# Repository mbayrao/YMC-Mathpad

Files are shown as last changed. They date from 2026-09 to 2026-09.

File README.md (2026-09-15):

# YMC-Mathpad

## **Overview**

這是我第一次用Git…有好多操作要學…Work on it...

這款鍵盤靈感來自Summa-Congni/Mathpad，當我在2025年的某日給女朋友看到能夠方便輸入數學符號的Mathpad
她知道我喜歡也能製做出電路板，便鼓勵我著手製作此project而誕生。
此板為第一版設計，製作時有許多問題導致設計不斷變更直到最後。
主要思路為無線藍芽連接內置5V USB Type C充電電路並提供電量指示燈、有OLED螢幕可供視覺回饋挑選符號

* **Wireless**：Buletooth 5
* **Screen Size**：0.96 inch
* **Layout**：正交排列,按鍵數量6(Maxium: 12) 鍵位配置為上、下、左、右、Enter及切換下一頁的Layer鍵
* **MCU**： ESP32-C3FH4
* **Firmware**：自訂韌體(使用Arduino IDE)
* **Battery life**： 5hrs(600mAh lithium batteries)
* **Mathematical Symbols**：56個符號(一頁14個，共四頁)，根據需求還可以再擴充
* **Dimension**：101mm x 87mm x 13mm

## **Features**

使用Gateron Low Profile THT軸體搭配白色矮鍵，
0.96吋雙色I2C OLED螢幕顯示現在電量、數學符號及實際發送文字

數學符號 

Layer1： ±×÷…≤≥≠√∑∏∞αβγ

Layer2： δεμφπσθ∈∉∫∂∆∇≈

Layer3： ≅≡∪∩≃≄∨∧∴∵⊆⊇⊂⊃

Layer4： ⊗⊕⊙∀∃ℕℤℚℝℍℙρ⇒⇔

## **Repository Contents**
此 Repository 包含自行製作一把鍵盤所需的所有檔案：

| Folder | Contents |
| ----- | ----- |
| `/hardware/pcb` | KiCad/Eagle 電路圖、PCB 佈局、Gerber 製造檔、BOM |
| `/hardware/cad` | CAD 原始檔（STEP）、外殼／定位板 STEP 輸出檔 |
| `/firmware` | 韌體原始碼 |

## **Build Instructions**

1. **PCB**：使用 `/hardware/pcb/gerbers` 中的 Gerber 製造檔，向 \[JLCPCB/PCBWay/其他\] 下單製作。  
2. **Case**：使用 `/hardware/cad` 中的 STEP 檔進行 3D 列印或 CNC 加工。  
4. **Firmware**：依照Arduino IDE方式進行韌體燒錄。

## **CAD / Case Files**

* **Format**：STEP（可編輯）、STL（可直接列印）  
* **Software used**：\[Fusion 360 / FreeCAD / SolidWorks\]  
* **Location**：`hardware/cad/`

## **Wiring / Schematic**

完整電路圖 PDF：[hardware/pcb/YMC_Mathpad_v1.pdf](https://github.com/mbayrao/YMC-Mathpad/blob/main/Hardware/YMC_Mathpad_v1.pdf)

## **Credits / Acknowledgments**

本專案受到 [Mathpad](https://github.com/Summa-Cogni/Mathpad)（作者：\[nup002\dancergraham]）的啟發，並以其為基礎進行開發。

## **Disclaimer**

本專案為業餘／開源專案，以「現況」提供，不提供任何保固。下單或焊接前，請確認所有元件的規格與額定值符合需求。

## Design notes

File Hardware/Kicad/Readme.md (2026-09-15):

Mathpad PCB files

This folder contains the schematics and design files for the Mathpad PCB.

The folder kicad contains the full KiCAD project file. Download the open source KiCAD EDA to open it.

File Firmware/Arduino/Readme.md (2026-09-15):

# This Firmware using 

 **libraries**

-NimBLE-Arduino(*IT WORKS ON VER.1.4.3*)

-BleKeyboard.h

-U8g2lib.h

-Keypad.h

 **LCD Image Converter tool**
* https://www.teachmemicro.com/lcd-bitmap-converter-online/

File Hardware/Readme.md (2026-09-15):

# Hardware resources

This folder contains everything related to the hardware of the Mathpad:
- Printed circuit board

The files contained in this folder are licensed under [CERN Open Hardware Licence Version 2 - Strongly Reciprocal](https://cern-ohl.web.cern.ch).

## What you CAN do:
- Use the design files to make products for yourself
- Modify the design files to suit your needs
- Share and distribute the original design files
- Share and distribute your modified design files
- Use the designs commercially and sell products you make

## What you MUST do:
- Keep all the original license notices and copyright information
- If you modify the files, add a notice stating what you changed and when
- When sharing products you've made, you must either:
	1) Provide the complete source files with the product, OR
	2) Clearly inform recipients where they can get the complete source files
- License any modifications you make under the same CERN-OHL-S license
- Display the source location on the product itself if specified in a notice

## What you CANNOT do:
- Remove or alter the original license notices
- Use a different license for your modifications
- Restrict others from exercising the rights granted by this license
- Hold the original creators liable for any issues with the designs

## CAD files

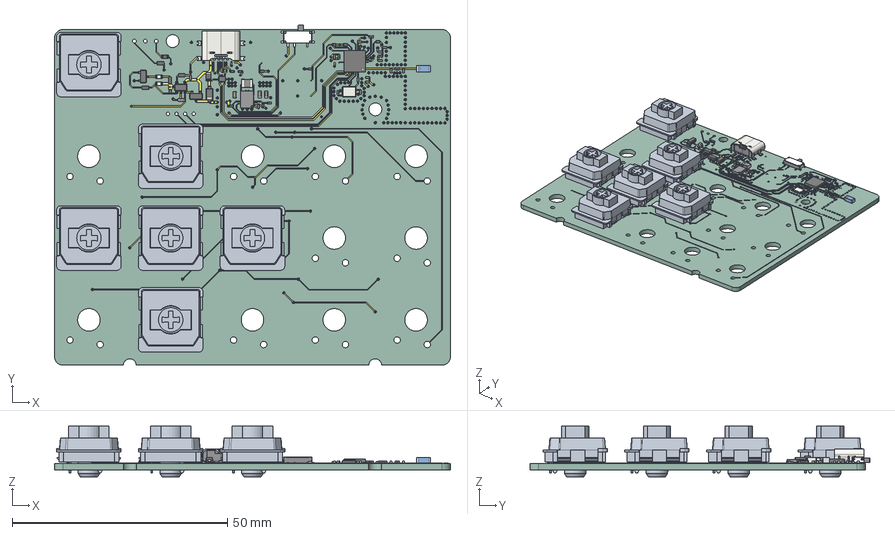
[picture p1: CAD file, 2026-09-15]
Hardware/Kicad/Mathpad.step
92.0 x 79.1 x 11.8 mm
R_0402_1005Metric x 11
LED_0603_1608Metric x 2
R_0603_1608Metric x 5
C_0402_1005Metric x 15
MSK12C02
D_SOD-123
SOT-23-5
Mathpad 1.11.1 x 6
QFN-32-1EP_5x5mm_P0.5mm_EP3.7x3.7mm
L_0402_1005Metric x 3
Crystal_SMD_3225-4Pin_3.2x2.5mm
ANT3216LL00R2400A
Fuse_0805_2012Metric
C_0603_1608Metric x 4
L_1008_2520Metric
SOT-666
ThermalPin
PinsArrayLR
SOT-23 x 2
USB_C_Receptacle_GCT_USB4135-GF-A_6P_TopMnt_Horizontal
Mathpad_copper
Mathpad_via
Mathpad_PCB

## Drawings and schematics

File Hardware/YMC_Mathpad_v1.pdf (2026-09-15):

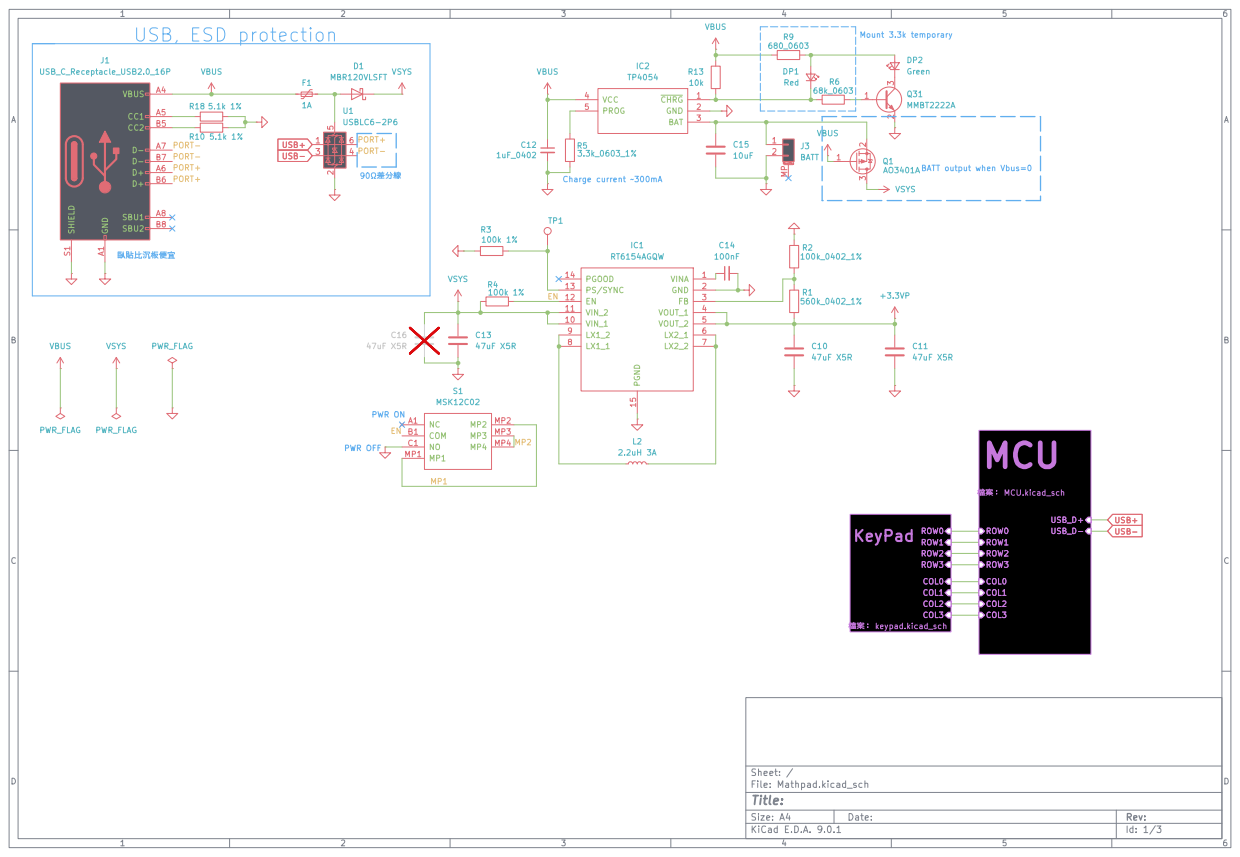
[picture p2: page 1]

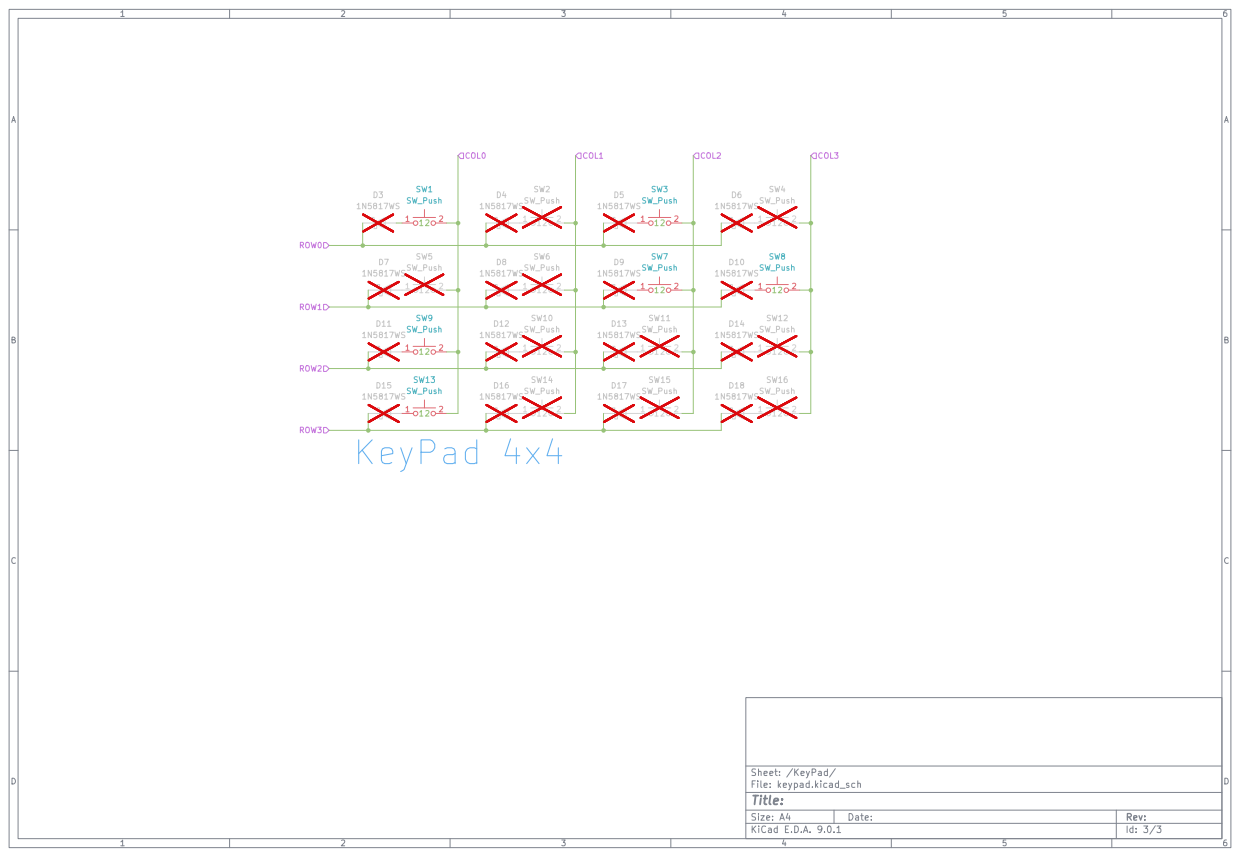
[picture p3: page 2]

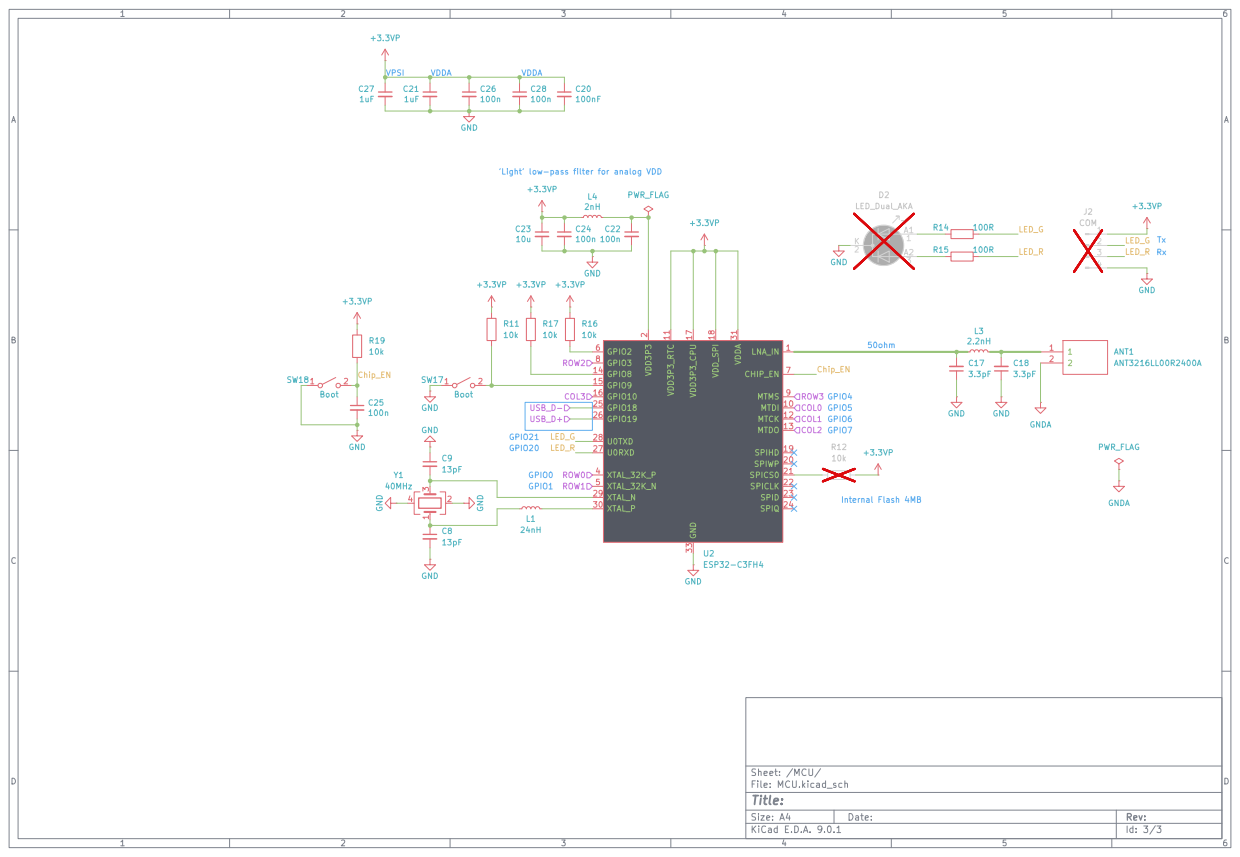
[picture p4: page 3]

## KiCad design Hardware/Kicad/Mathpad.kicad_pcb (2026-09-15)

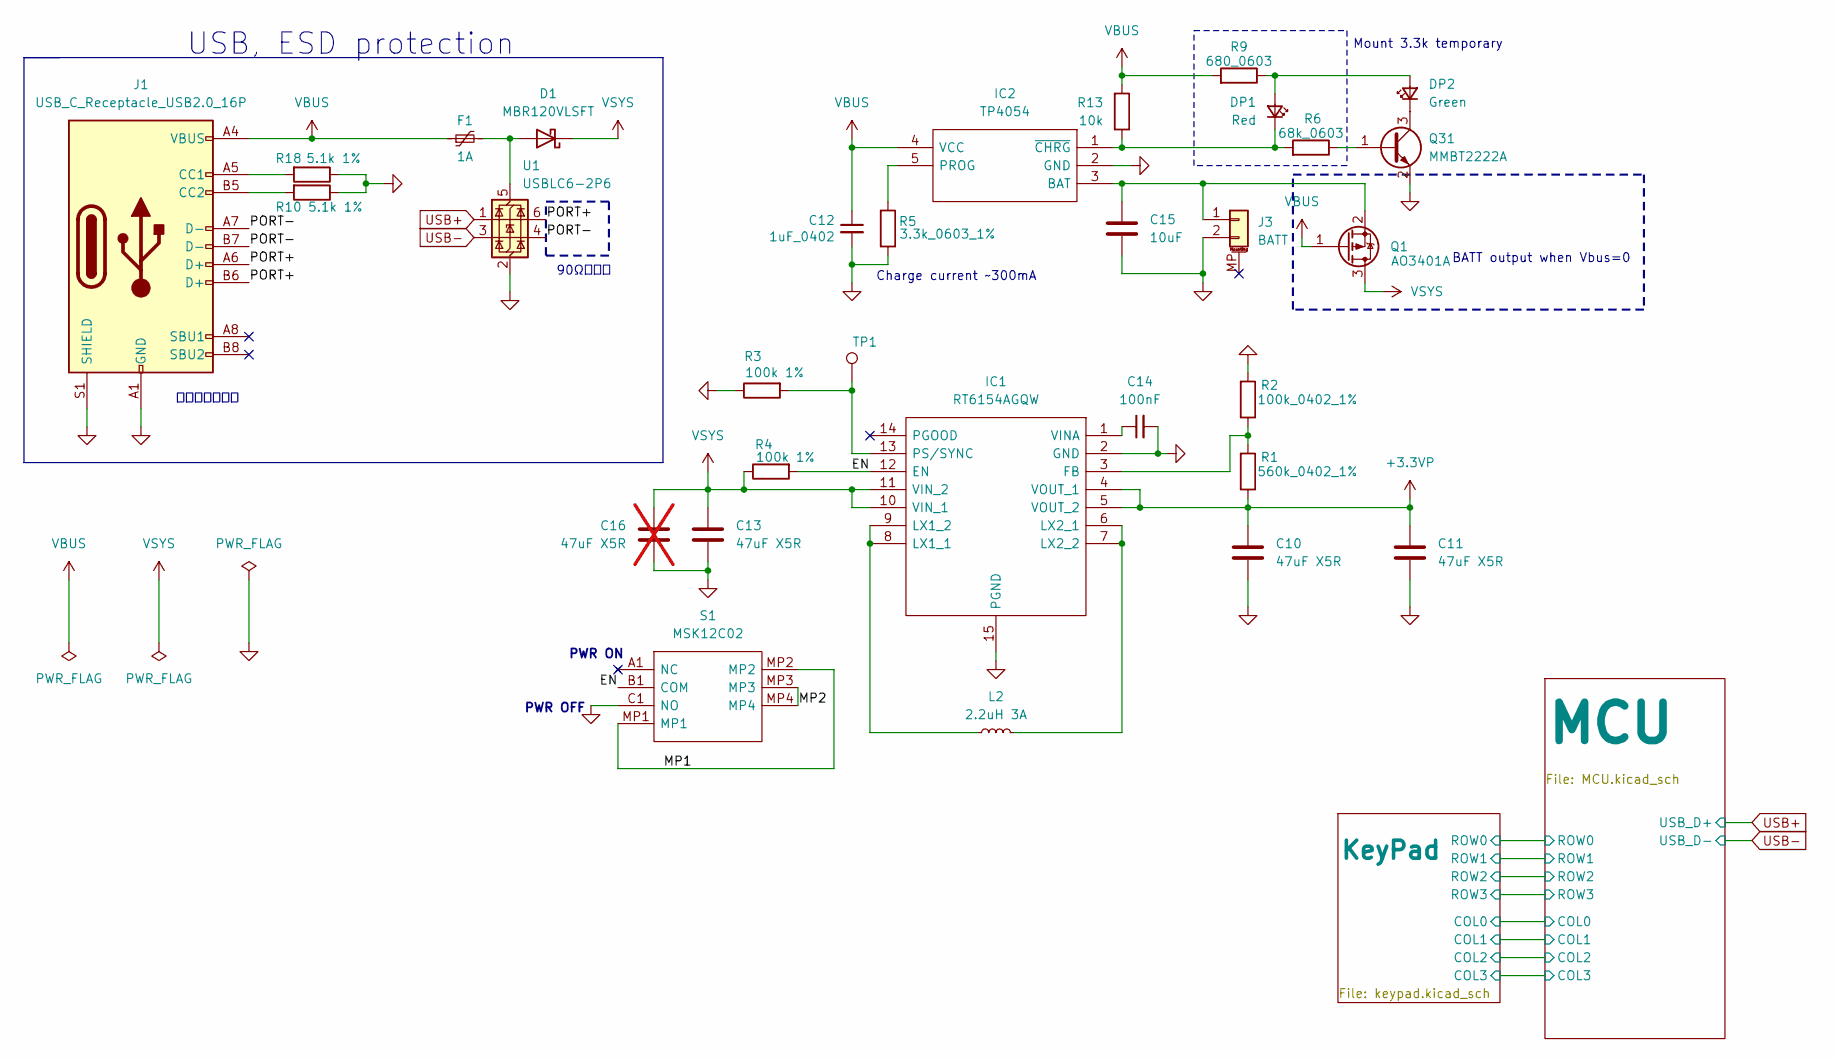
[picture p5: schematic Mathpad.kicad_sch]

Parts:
C10, C11, C13: 47uF X5R; C_0603_1608Metric; LCSC Part # C140782
C12: 1uF_0402; C_0402_1005Metric; LCSC Part # C52923
C14: 100nF; C_0402_1005Metric; LCSC Part # C85858
C15: 10uF; C_0603_1608Metric; LCSC Part # C6119842
C16: 47uF X5R; C_0603_1608Metric; LCSC Part # C140782; not fitted
D1: MBR120VLSFT; D_SOD-123; LCSC Part # C223608
DP1: Red; LED_0603_1608Metric; LCSC Part # C965799
DP2: Green; LED_0603_1608Metric; LCSC Part # C22371297
F1: 1A; Fuse_0805_2012Metric; MPN BSMD0805-050-24V; LCSC C910822
IC1: RT6154AGQW; SON50P300X400X80-15N-D; Manufacturer_Part_Number RT6154AGQW; Mouser Part Number 835-RT6154AGQW
IC2: TP4054; SOT-23-5; Manufacturer_Part_Number TP4054; LCSC Part # C5381776
J1: USB_C_Receptacle_USB2.0_16P; USB_C_Receptacle_GCT_USB4110; LCSC Part # C5187472
J3: BATT; JST_ZH_S2B-ZR-SM4A-TF_1x02-1MP_P1.50mm_Horizontal; LCSC Part # C19272405
L2: 2.2uH 3A; L_1008_2520Metric; LCSC Part # C5832372
Q1: AO3401A; SOT-23; LCSC Part # C15127
Q31: MMBT2222A; SOT-23; LCSC Part # C82460
R1: 560k_0402_1%; R_0402_1005Metric; MPN 0402WGF5101TCE; LCSC C137958
R2: 100k_0402_1%; R_0402_1005Metric; MPN 0402WGF5101TCE; LCSC C60491
R3, R4: 100k 1%; R_0402_1005Metric; MPN 0402WGF5101TCE; LCSC C60491
R5: 3.3k_0603_1%; R_0603_1608Metric; LCSC C22978
R6: 68k_0603; R_0603_1608Metric; LCSC C22978
R9: 680_0603; R_0603_1608Metric; LCSC C22978
R10, R18: 5.1k 1%; R_0402_1005Metric; MPN 0402WGF5101TCE; LCSC C25905
R13: 10k; R_0402_1005Metric; LCSC Part # C60490
S1: MSK12C02; Manufacturer_Part_Number MSK12C02; LCSC Part # C431540
TP1: TestPoint; TestPoint_Pad_1.5x1.5mm
U1: USBLC6-2P6; SOT-666; LCSC Part # C15999

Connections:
+3.3VP: C10.1, C11.1, IC1.4 (VOUT_1), IC1.5 (VOUT_2), R1.1; also elsewhere on the board
/EN: IC1.12 (EN), R4.2, S1.B1 (COM)
/MP1: S1.MP1, S1.MP2
/MP2: S1.MP3, S1.MP4
/PORT+: J1.A6 (D+), J1.B6 (D+), U1.6 (I/O1)
/PORT-: J1.A7 (D-), J1.B7 (D-), U1.4 (I/O2)
GND: C10.2, C11.2, C12.2, C13.2, C14.2, C15.2, C16.2, IC1.2 (GND), IC1.15 (PGND), IC2.2 (GND), J1.A1 (GND), J1.A12 (GND), J1.B1 (GND), J1.B12 (GND), J1.S1 (SHIELD), J3.2, Q31.2 (E), R2.2, R3.1, R5.1, R10.1, R18.1, S1.C1 (NO), U1.2 (GND); also elsewhere on the board
unnamed: D1.2 (A), F1.2, U1.5 (VBUS)
unnamed: DP1.1 (K), IC2.1 (~CHRG), R6.2, R13.1
unnamed: DP2.1 (K), Q31.3 (C)
unnamed: IC1.3 (FB), R1.2, R2.1
unnamed: IC1.8 (LX1_1), IC1.9 (LX1_2), L2.2
unnamed: IC1.6 (LX2_1), IC1.7 (LX2_2), L2.1
unnamed: IC1.13 (PS/SYNC), R3.2, TP1.1
unnamed: C14.1, IC1.1 (VINA)
unnamed: C15.1, IC2.3 (BAT), J3.1, Q1.2 (S)
unnamed: IC2.5 (PROG), R5.2
unnamed: J1.A5 (CC1), R18.2
unnamed: J1.B5 (CC2), R10.2
unnamed: Q31.1 (B), R6.1
USB+: U1.1 (I/O1); also elsewhere on the board
USB-: U1.3 (I/O2); also elsewhere on the board
VSYS: C13.1, C16.1, D1.1 (K), IC1.10 (VIN_1), IC1.11 (VIN_2), Q1.3 (D), R4.1

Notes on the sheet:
90Ω差分線
USB, ESD protection
Mount 3.3k temporary
PWR ON
PWR OFF
臥貼比沉板便宜
Charge current ~300mA
BATT output when Vbus=0

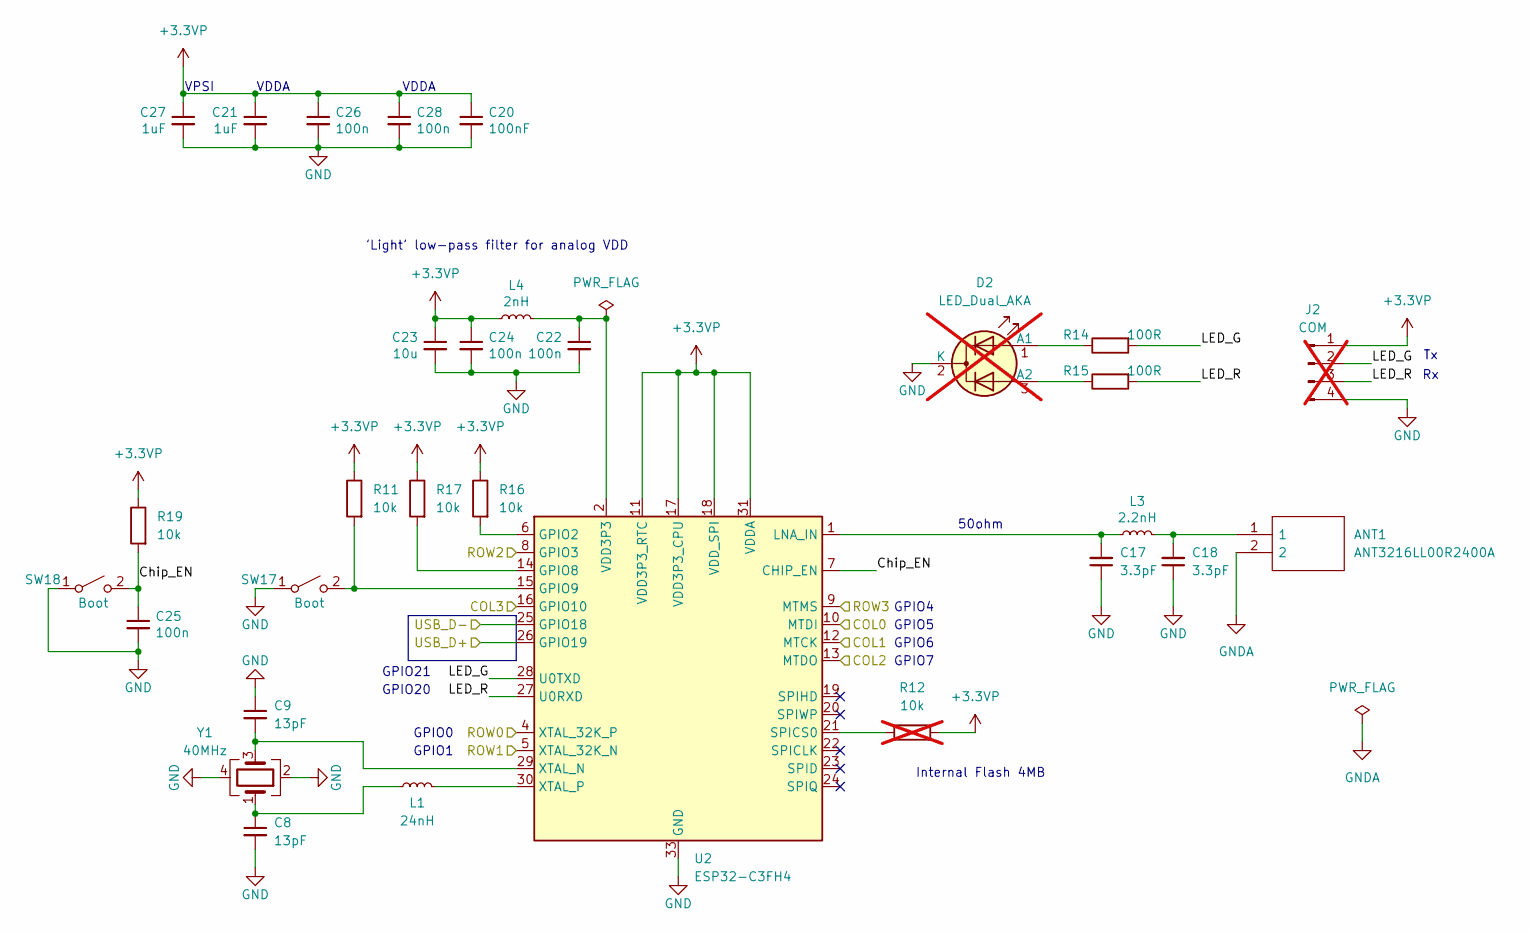
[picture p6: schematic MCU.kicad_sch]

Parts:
ANT1: ANT3216LL00R2400A; Manufacturer_Part_Number ANT3216LL00R2400A; Mouser Part Number 603-ANT3216LL00R2400
C8, C9: 13pF; C_0402_1005Metric; LCSC Part # C45359988
C17, C18: 3.3pF; C_0402_1005Metric; LCSC Part # C76906
C20: 100nF; C_0402_1005Metric; LCSC Part # C1525
C21, C27: 1uF; C_0402_1005Metric; LCSC Part # C52923
C22, C24, C25, C26, C28: 100n; C_0402_1005Metric; LCSC Part # C1525
C23: 10u; C_0402_1005Metric; LCSC Part # C76991
D2: LED_Dual_AKA; LED_D3.0mm-3; not fitted
J2: COM; PinHeader_1x04_P2.00mm_Vertical; not fitted
L1: 24nH; L_0402_1005Metric; LCSC Part # C330863
L3: 2.2nH; L_0402_1005Metric; LCSC Part # C86061
L4: 2nH; L_0402_1005Metric; LCSC Part # C18216
R11, R16, R17, R19: 10k; R_0402_1005Metric; LCSC Part # C60490
R12: 10k; R_0402_1005Metric; LCSC Part # C60490; not fitted
R14, R15: 100R; R_0603_1608Metric; LCSC Part # C105588
SW17, SW18: Boot; SW_Push_SPST_NO_Alps_SKRK; LCSC Part # C18077675
U2: ESP32-C3FH4; QFN-32-1EP_5x5mm_P0.5mm_EP3.7x3.7mm; LCSC Part # C2858491
Y1: 40MHz; Crystal_SMD_3225-4Pin_3.2x2.5mm; LCSC Part # C18221407

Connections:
+3.3VP: C20.1, C21.1, C23.1, C24.1, C26.1, C27.1, C28.1, J2.1, L4.1, R11.1, R12.2, R16.1, R17.1, R19.1, U2.11 (VDD3P3_RTC), U2.17 (VDD3P3_CPU), U2.18 (VDD_SPI), U2.31 (VDDA), U2.32 (VDDA); also elsewhere on the board
/KeyPad/COL0: U2.10 (MTDI); also elsewhere on the board
/KeyPad/COL1: U2.12 (MTCK); also elsewhere on the board
/KeyPad/COL2: U2.13 (MTDO); also elsewhere on the board
/KeyPad/COL3: U2.16 (GPIO10); also elsewhere on the board
/KeyPad/ROW0: U2.4 (XTAL_32K_P); also elsewhere on the board
/KeyPad/ROW1: U2.5 (XTAL_32K_N); also elsewhere on the board
/KeyPad/ROW2: U2.8 (GPIO3); also elsewhere on the board
/KeyPad/ROW3: U2.9 (MTMS); also elsewhere on the board
/MCU/Chip_EN: C25.1, R19.2, SW18.2 (B), U2.7 (CHIP_EN)
/MCU/LED_G: J2.2, R14.2, U2.28 (U0TXD)
/MCU/LED_R: J2.3, R15.2, U2.27 (U0RXD)
GND: C8.2, C9.1, C17.1, C18.1, C20.2, C21.2, C22.2, C23.2, C24.2, C25.2, C26.2, C27.2, C28.2, D2.2 (K), J2.4, SW17.1 (A), SW18.1 (A), U2.33 (GND), Y1.2, Y1.4; also elsewhere on the board
GNDA: ANT1.2
unnamed: ANT1.1, C18.2, L3.2
unnamed: C8.1, L1.1, Y1.1
unnamed: C22.1, L4.2, U2.2 (VDD3P3), U2.3 (VDD3P3)
unnamed: D2.1 (A1), R14.1
unnamed: D2.3 (A2), R15.1
unnamed: R11.2, SW17.2 (B), U2.15 (GPIO9)
unnamed: R16.2, U2.6 (GPIO2)
unnamed: R17.2, U2.14 (GPIO8)
unnamed: C17.2, L3.1, U2.1 (LNA_IN)
unnamed: R12.1, U2.21 (SPICS0)
unnamed: C9.2, U2.29 (XTAL_N), Y1.3
unnamed: L1.2, U2.30 (XTAL_P)
USB+: U2.26 (GPIO19); also elsewhere on the board
USB-: U2.25 (GPIO18); also elsewhere on the board

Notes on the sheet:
GPIO1
GPIO4
GPIO5
VPSI
GPIO6
VDDA
GPIO20
GPIO21
GPIO7
GPIO0
'Light' low-pass filter for analog VDD
50ohm
Internal Flash 4MB

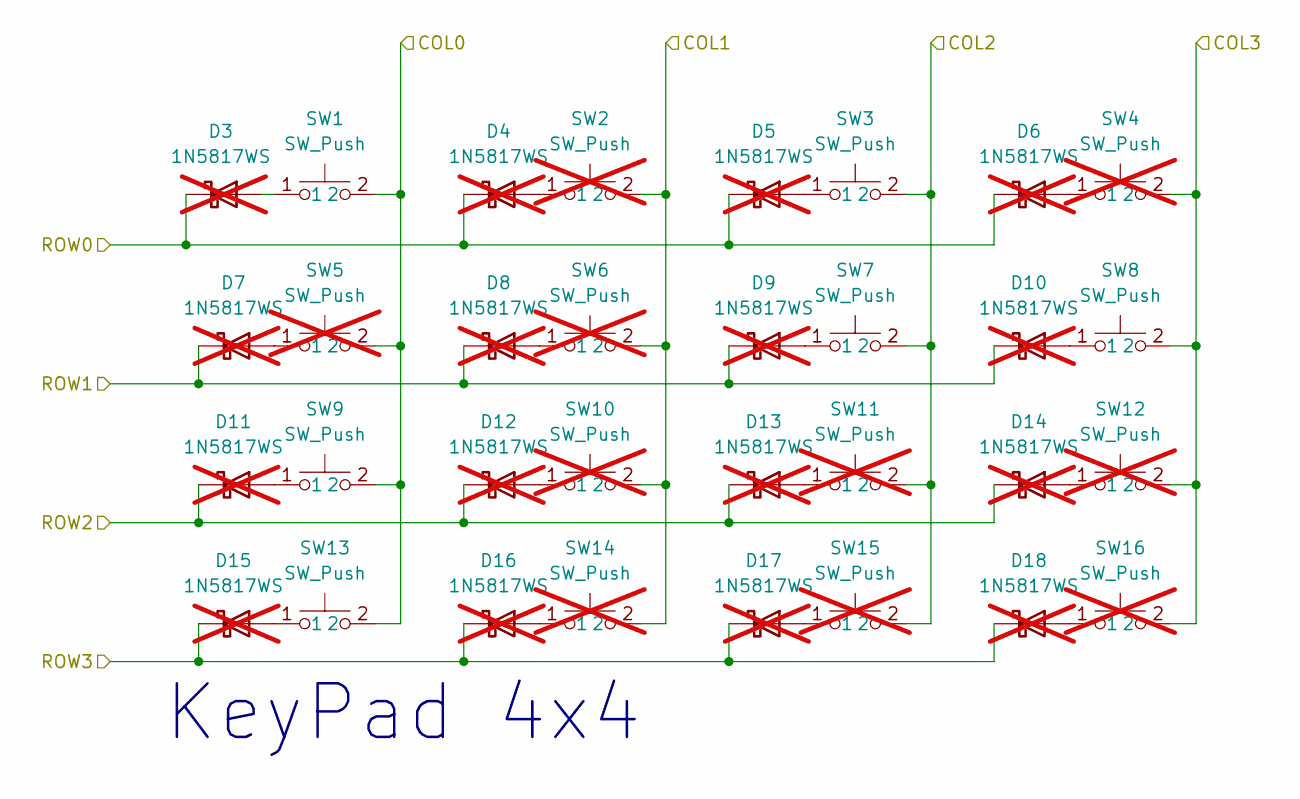
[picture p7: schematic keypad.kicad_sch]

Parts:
D3, D4, D5, D6, D7, D8, D9, D10, D11, D12, D13, D14, D15, D16, D17, D18: 1N5817WS; D_SOD-123; LCSC Part # C727113; not fitted
SW1, SW3, SW7, SW8, SW9, SW13: SW_Push; SW_Gateron_LowProfile_THT
SW2, SW4, SW5, SW6, SW10, SW11, SW12, SW14, SW15, SW16: SW_Push; SW_Gateron_LowProfile_THT; not fitted

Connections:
/KeyPad/COL0: SW1.2, SW5.2, SW9.2, SW13.2; also elsewhere on the board
/KeyPad/COL1: SW2.2, SW6.2, SW10.2, SW14.2; also elsewhere on the board
/KeyPad/COL2: SW3.2, SW7.2, SW11.2, SW15.2; also elsewhere on the board
/KeyPad/COL3: SW4.2, SW8.2, SW12.2, SW16.2; also elsewhere on the board
/KeyPad/ROW0: D3.1 (K), D4.1 (K), D5.1 (K), D6.1 (K); also elsewhere on the board
/KeyPad/ROW1: D7.1 (K), D8.1 (K), D9.1 (K), D10.1 (K); also elsewhere on the board
/KeyPad/ROW2: D11.1 (K), D12.1 (K), D13.1 (K), D14.1 (K); also elsewhere on the board
/KeyPad/ROW3: D15.1 (K), D16.1 (K), D17.1 (K), D18.1 (K); also elsewhere on the board
unnamed: D3.2 (A), SW1.1
unnamed: D4.2 (A), SW2.1
unnamed: D5.2 (A), SW3.1
unnamed: D6.2 (A), SW4.1
unnamed: D7.2 (A), SW5.1
unnamed: D8.2 (A), SW6.1
unnamed: D9.2 (A), SW7.1
unnamed: D10.2 (A), SW8.1
unnamed: D11.2 (A), SW9.1
unnamed: D12.2 (A), SW10.1
unnamed: D13.2 (A), SW11.1
unnamed: D14.2 (A), SW12.1
unnamed: D15.2 (A), SW13.1
unnamed: D16.2 (A), SW14.1
unnamed: D17.2 (A), SW15.1
unnamed: D18.2 (A), SW16.1

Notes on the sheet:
KeyPad 4x4

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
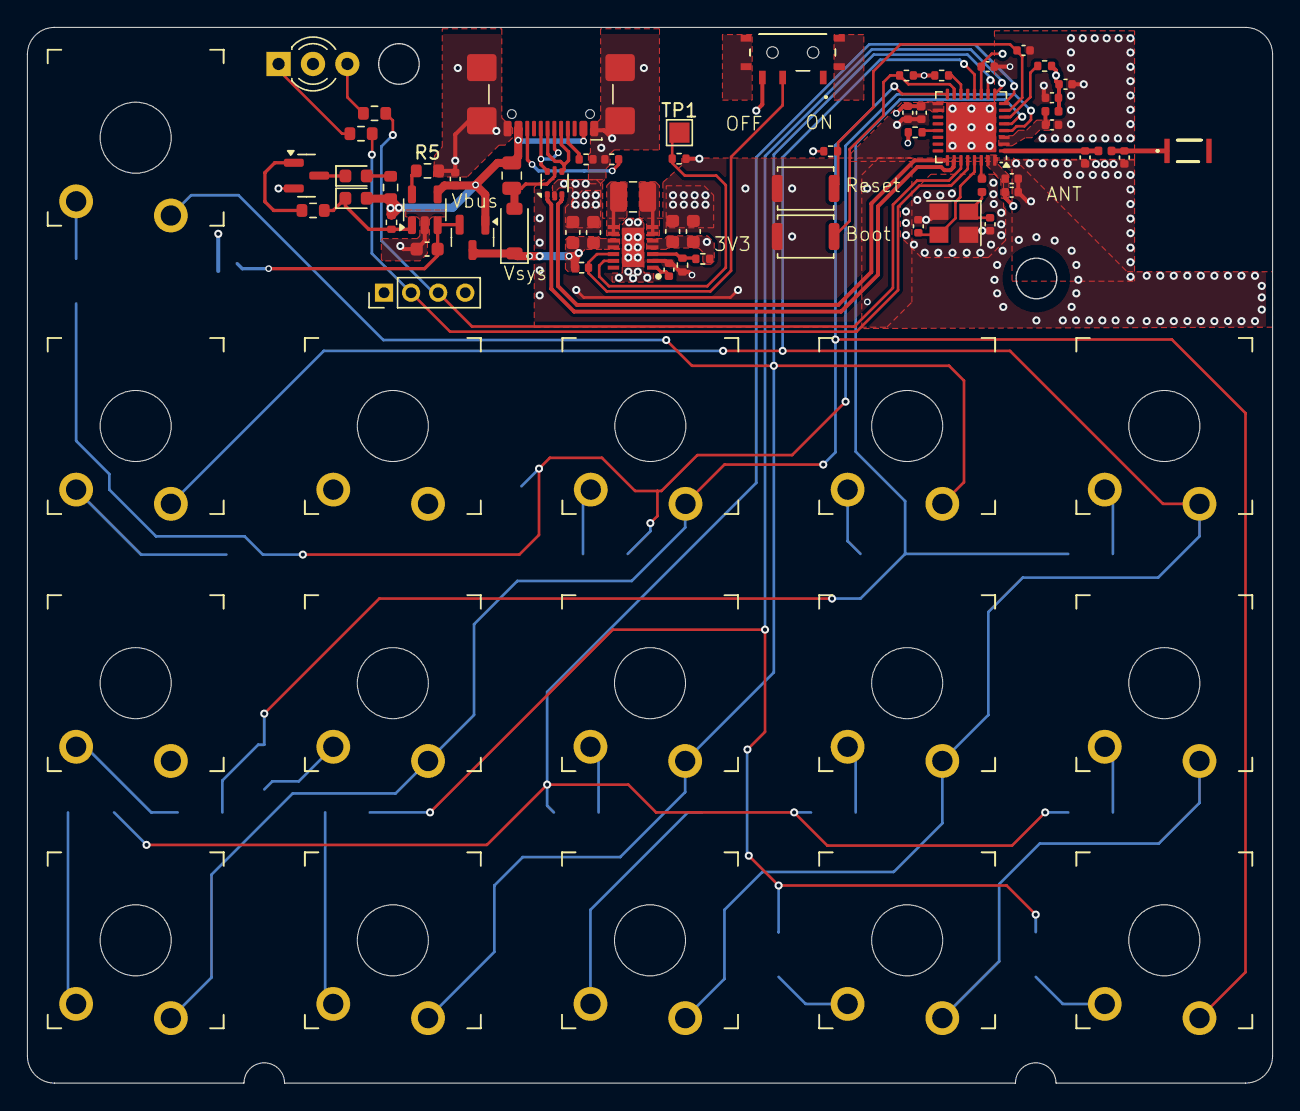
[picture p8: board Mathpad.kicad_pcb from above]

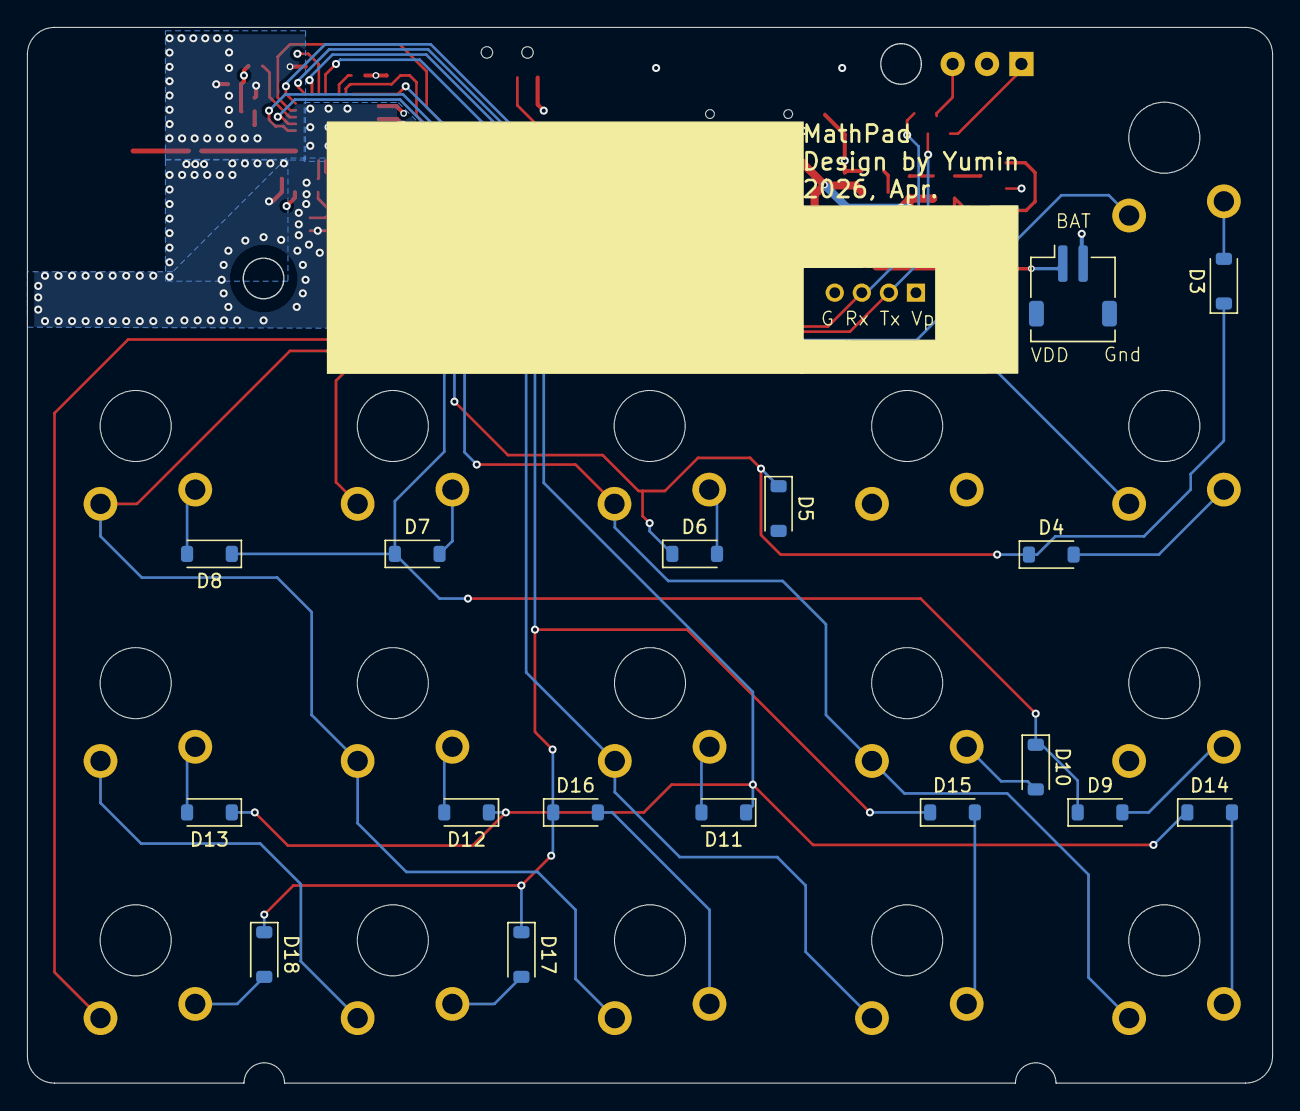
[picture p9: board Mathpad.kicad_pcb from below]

Board: 4 copper layers, 92.0 x 78.0 mm, 93 parts (17 on the bottom side), 64 nets.

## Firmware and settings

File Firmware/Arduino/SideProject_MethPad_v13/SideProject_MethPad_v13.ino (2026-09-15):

// v13 - add Layer 4
#include <BleKeyboard.h>
BleKeyboard bleKeyboard("YMC-BLE_KB", "Mendako Lab", 50); // 50 僅為初始宣告值
#define USE_NIMBLE

#include <Wire.h>
#include <U8g2lib.h>
#include <Keypad.h>

U8G2_SSD1306_128X64_NONAME_F_HW_I2C u8g2(U8G2_R0, /* reset=*/ U8X8_PIN_NONE, /* clock=*/ 21, /* data=*/ 20);

// --- 2x4 鍵盤設定 ---
const byte ROWS = 2; 
const byte COLS = 4; 
char keys[ROWS][COLS] = {
  { 1, 2, 3, 4 },
  { 5, 6, 7, 8 }
};
byte rowPins[ROWS] = { 0, 1 };      
byte colPins[COLS] = { 5, 6, 7, 10 }; 
Keypad keypad = Keypad(makeKeymap(keys), rowPins, colPins, ROWS, COLS);

// --- 電池偵測硬體設定 ---
#define BATTERY_PIN 3            // 電池分壓接至 GPIO3
int batteryLevel = 100;          // 全域變數：儲存目前的電量百分比 (0-100)
unsigned long lastBatteryCheck = 0; // 記錄上次檢查電池的時間
const unsigned long batteryInterval = 5000; // 每 60,000 毫秒 (1分鐘) 檢查一次

// --- 狀態變數 ---
uint8_t currentLayer = 1; 
int currentCursor = 0;    
float adcValue=0;
int percentage=0;
// ---- LaTeX 輸出字串對應 ----
const char* symbolShortcuts[4][14] = {
  { "\\pm%/#",     "\\times%/#",    "\\div%/#",  "\\dots%/#",   "\\le%/#",     "\\ge%/#",     "\\neq%/#",    "\\sqrt%/#",   "\\sum%/#",        "\\prod%/#",     "\\infty%/#",    "\\alpha%/#",    "\\beta%/#",    "\\gamma%/#"   },
  { "\\delta%/#",  "\\epsilon%/#",  "\\mu%/#",   "\\phi%/#",    "\\pi%/#",     "\\sigma%/#",  "\\theta%/#",  "\\in%/#",     "\\nin%/#",        "\\int%/#",      "\\partial%/#",  "\\Delta%/#",    "\\nabla%/#",   "\\approx%/#", },
  { "\\cong%/#",   "\\equiv%/#",    "\\cup%/#",  "\\cap%/#",    "\\simeq%/#",  "\\not%/#",    "\\vee%/#",    "\\wedge%/#",  "\\therefore%/#",  "\\because%/#",  "\\sube%/#",     "\\supe%/#",     "\\sub%/#",     "\\sup%/#",    },
  { "\\krone%/#",  "\\exclus%/#",   "\\hadam%/#","\\forall%/#", "\\existe%/#", "\\natur%/#",  "\\integ%/#",  "\\ratio%/#",  "\\real%/#",       "\\Quat%/#",     "\\prime%/#",    "\\rho%/#",      "\\ifthen%/#",  "\\ifaoif%/#"}
};


// =========================================================================
// https://www.teachmemicro.com/lcd-bitmap-converter-online/
// =========================================================================

// --- LAYER 1 (共14個) ---
const uint8_t bmp_L1_0[32] PROGMEM = { 0x00,0x00,0x01,0x80,0x01,0x80,0x01,0x80,0x01,0x80,0x1F,0xF8,0x1F,0xF8,0x01,0x80,0x01,0x80,0x01,0x80,0x01,0x80,0x00,0x00,0x1F,0xF8,0x1F,0xF8,0x00,0x00,0x00,0x00 }; // ±
const uint8_t bmp_L1_1[32] PROGMEM = { 0x00,0x00,0x00,0x00,0x00,0x00,0x10,0x08,0x08,0x10,0x04,0x20,0x02,0x40,0x01,0x80,0x01,0x80,0x02,0x40,0x04,0x20,0x08,0x10,0x10,0x08,0x00,0x00,0x00,0x00,0x00,0x00 }; // ×
const uint8_t bmp_L1_2[32] PROGMEM = { 0x00,0x00,0x00,0x00,0x00,0x00,0x00,0x00,0x01,0x80,0x01,0x80,0x00,0x00,0x1F,0xF8,0x1F,0xF8,0x00,0x00,0x01,0x80,0x01,0x80,0x00,0x00,0x00,0x00,0x00,0x00,0x00,0x00 }; // ÷
const uint8_t bmp_L1_3[32] PROGMEM = { 0x00,0x00,0x00,0x00,0x00,0x00,0x00,0x00,0x00,0x00,0x00,0x00,0x00,0x00,0x00,0x00,0x00,0x00,0x00,0x00,0x00,0x00,0x33,0x30,0x33,0x30,0x00,0x00,0x00,0x00,0x00,0x00 }; // …
const uint8_t bmp_L1_4[32] PROGMEM = { 0x00,0x00,0x00,0x00,0x00,0x00,0x00,0x18,0x00,0x60,0x01,0x80,0x06,0x00,0x18,0x00,0x06,0x00,0x01,0x80,0x00,0x60,0x00,0x18,0x00,0x00,0x1F,0xF8,0x00,0x00,0x00,0x00 }; // ≤
const uint8_t bmp_L1_5[32] PROGMEM = { 0x00,0x00,0x00,0x00,0x00,0x00,0x18,0x00,0x06,0x00,0x01,0x80,0x00,0x60,0x00,0x18,0x00,0x60,0x01,0x80,0x06,0x00,0x18,0x00,0x00,0x00,0x1F,0xF8,0x00,0x00,0x00,0x00 }; // ≥
const uint8_t bmp_L1_6[32] PROGMEM = { 0x00,0x00,0x00,0x00,0x00,0x00,0x00,0x08,0x00,0x10,0x00,0x20,0x1F,0xF8,0x00,0x80,0x01,0x00,0x1F,0xF8,0x04,0x00,0x08,0x00,0x10,0x00,0x00,0x00,0x00,0x00,0x00,0x00 }; // ≠
const uint8_t bmp_L1_7[32] PROGMEM = { 0x00,0x00,0x00,0x00,0x00,0x0E,0x00,0x10,0x00,0x10,0x00,0x20,0x00,0x20,0x00,0x40,0x30,0x40,0x08,0x80,0x08,0x80,0x05,0x00,0x05,0x00,0x02,0x00,0x02,0x00,0x00,0x00 }; // √
const uint8_t bmp_L1_8[32] PROGMEM = { 0x00,0x00,0x00,0x00,0x1F,0xF8,0x10,0x18,0x08,0x08,0x04,0x00,0x02,0x00,0x01,0x00,0x00,0x80,0x01,0x00,0x02,0x00,0x04,0x00,0x08,0x08,0x10,0x18,0x1F,0xF8,0x00,0x00 }; // ∑
const uint8_t bmp_L1_9[32] PROGMEM = { 0x00,0x00,0x00,0x00,0x00,0x00,0x1F,0xF8,0x04,0x20,0x04,0x20,0x04,0x20,0x04,0x20,0x04,0x20,0x04,0x20,0x04,0x20,0x04,0x20,0x04,0x20,0x00,0x00,0x00,0x00,0x00,0x00 }; // ∏
const uint8_t bmp_L1_10[32] PROGMEM= { 0x00,0x00,0x00,0x00,0x00,0x00,0x00,0x00,0x00,0x00,0x00,0x00,0x0C,0x18,0x12,0x24,0x21,0x42,0x20,0x82,0x21,0x42,0x12,0x24,0x0C,0x18,0x00,0x00,0x00,0x00,0x00,0x00 }; // ∞
const uint8_t bmp_L1_11[32] PROGMEM= { 0x00,0x00,0x00,0x00,0x00,0x00,0x00,0x00,0x00,0x00,0x07,0x20,0x08,0xA0,0x08,0x40,0x08,0x40,0x08,0x40,0x08,0x40,0x08,0xA0,0x07,0x20,0x00,0x00,0x00,0x00,0x00,0x00 }; // α
const uint8_t bmp_L1_12[32] PROGMEM= { 0x00,0x00,0x00,0x00,0x07,0x00,0x08,0x80,0x08,0x80,0x08,0x80,0x0F,0x80,0x08,0x40,0x08,0x40,0x08,0x40,0x0C,0x40,0x0B,0x80,0x08,0x00,0x08,0x00,0x00,0x00,0x00,0x00 }; // β
const uint8_t bmp_L1_13[32] PROGMEM= { 0x00,0x00,0x00,0x00,0x00,0x00,0x00,0x00,0x10,0x80,0x08,0x80,0x08,0x80,0x05,0x00,0x05,0x00,0x05,0x00,0x02,0x00,0x02,0x00,0x02,0x00,0x00,0x00,0x00,0x00,0x00,0x00 }; // γ

// --- LAYER 2 (共14個) ---
const uint8_t bmp_L2_0[32] PROGMEM = { 0x00,0x00,0x00,0x00,0x00,0x00,0x00,0x00,0x00,0x00,0x01,0x80,0x02,0x00,0x02,0x00,0x01,0x00,0x02,0x80,0x04,0x40,0x04,0x40,0x03,0x80,0x00,0x00,0x00,0x00,0x00,0x00 }; // δ
const uint8_t bmp_L2_1[32] PROGMEM = { 0x00,0x00,0x00,0x00,0x00,0x00,0x00,0x00,0x00,0x00,0x07,0x80,0x08,0x40,0x08,0x00,0x07,0x80,0x08,0x00,0x08,0x00,0x08,0x40,0x07,0x80,0x00,0x00,0x00,0x00,0x00,0x00 }; // ε
const uint8_t bmp_L2_2[32] PROGMEM = { 0x00,0x00,0x00,0x00,0x00,0x00,0x00,0x00,0x08,0x40,0x08,0x40,0x08,0x40,0x08,0x40,0x08,0x40,0x0C,0xC0,0x0B,0x20,0x08,0x00,0x08,0x00,0x00,0x00,0x00,0x00,0x00,0x00 }; // μ
const uint8_t bmp_L2_3[32] PROGMEM = { 0x00,0x00,0x00,0x00,0x00,0x00,0x01,0x00,0x01,0x00,0x07,0xC0,0x09,0x20,0x09,0x20,0x09,0x20,0x09,0x20,0x07,0xC0,0x01,0x00,0x01,0x00,0x00,0x00,0x00,0x00,0x00,0x00 }; // φ
const uint8_t bmp_L2_4[32] PROGMEM = { 0x00,0x00,0x00,0x00,0x00,0x00,0x00,0x00,0x00,0x00,0x1F,0xF0,0x04,0x40,0x04,0x40,0x04,0x40,0x04,0x40,0x04,0x40,0x04,0x40,0x08,0x70,0x00,0x00,0x00,0x00,0x00,0x00 }; // π
const uint8_t bmp_L2_5[32] PROGMEM = { 0x00,0x00,0x00,0x00,0x00,0x00,0x00,0x00,0x00,0x00,0x03,0xE0,0x04,0x80,0x04,0x40,0x04,0x40,0x04,0x40,0x04,0x40,0x04,0x40,0x03,0x80,0x00,0x00,0x00,0x00,0x00,0x00 }; // σ
const uint8_t bmp_L2_6[32] PROGMEM = { 0x00,0x00,0x00,0x00,0x01,0x80,0x02,0x40,0x04,0x20,0x04,0x20,0x04,0x20,0x07,0xE0,0x04,0x20,0x04,0x20,0x04,0x20,0x02,0x40,0x01,0x80,0x00,0x00,0x00,0x00,0x00,0x00 }; // θ
const uint8_t bmp_L2_7[32] PROGMEM = { 0x00,0x00,0x00,0x00,0x00,0x00,0x07,0xC0,0x08,0x00,0x10,0x00,0x20,0x00,0x3F,0xC0,0x20,0x00,0x10,0x00,0x08,0x00,0x07,0xC0,0x00,0x00,0x00,0x00,0x00,0x00,0x00,0x00 }; // ∈
const uint8_t bmp_L2_8[32] PROGMEM = { 0x00,0x00,0x00,0x00,0x00,0x20,0x07,0xC0,0x08,0x40,0x10,0x80,0x21,0x00,0x3F,0xC0,0x22,0x00,0x14,0x00,0x08,0x00,0x17,0xC0,0x20,0x00,0x00,0x00,0x00,0x00,0x00,0x00 }; // ∉
const uint8_t bmp_L2_9[32] PROGMEM = { 0x00,0x00,0x00,0x00,0x00,0x00,0x01,0x80,0x02,0x00,0x02,0x00,0x02,0x00,0x02,0x00,0x02,0x00,0x02,0x00,0x02,0x00,0x02,0x00,0x0C,0x00,0x00,0x00,0x00,0x00,0x00,0x00 }; // ∫
const uint8_t bmp_L2_10[32] PROGMEM= { 0x00,0x00,0x00,0x00,0x00,0x00,0x00,0x00,0x01,0xC0,0x02,0x20,0x00,0x20,0x01,0xA0,0x02,0x60,0x04,0x20,0x04,0x20,0x04,0x40,0x03,0x80,0x00,0x00,0x00,0x00,0x00,0x00 }; // ∂
const uint8_t bmp_L2_11[32] PROGMEM= { 0x00,0x00,0x00,0x00,0x00,0x00,0x01,0x00,0x01,0x00,0x02,0x80,0x02,0x80,0x04,0x40,0x04,0x40,0x04,0x40,0x08,0x20,0x08,0x20,0x0F,0xE0,0x00,0x00,0x00,0x00,0x00,0x00 }; // ∆
const uint8_t bmp_L2_12[32] PROGMEM= { 0x00,0x00,0x00,0x00,0x00,0x00,0x0F,0xE0,0x08,0x20,0x08,0x20,0x04,0x40,0x04,0x40,0x04,0x40,0x02,0x80,0x02,0x80,0x01,0x00,0x01,0x00,0x00,0x00,0x00,0x00,0x00,0x00 }; // ∇
const uint8_t bmp_L2_13[32] PROGMEM= { 0x00,0x00,0x00,0x00,0x00,0x00,0x00,0x00,0x00,0x00,0x00,0x00,0x07,0x04,0x08,0x88,0x10,0x70,0x07,0x04,0x08,0x88,0x10,0x70,0x00,0x00,0x00,0x00,0x00,0x00,0x00,0x00 }; // ≈


// --- LAYER 3 (共14個) ---
const uint8_t bmp_L3_0[32] PROGMEM = { 0x00,0x00,0x00,0x00,0x00,0x00,0x00,0x00,0x00,0x00,0x00,0x00,0x07,0x04,0x08,0x88,0x10,0x70,0x00,0x00,0x1F,0xFC,0x00,0x00,0x1F,0xFC,0x00,0x00,0x00,0x00,0x00,0x00 }; // ≅
const uint8_t bmp_L3_1[32] PROGMEM = { 0x00,0x00,0x00,0x00,0x00,0x00,0x00,0x00,0x00,0x00,0x00,0x00,0x0F,0xF0,0x00,0x00,0x00,0x00,0x0F,0xF0,0x00,0x00,0x00,0x00,0x0F,0xF0,0x00,0x00,0x00,0x00,0x00,0x00 }; // ≡
const uint8_t bmp_L3_2[32] PROGMEM = { 0x00,0x00,0x00,0x00,0x00,0x00,0x00,0x00,0x10,0x08,0x10,0x08,0x10,0x08,0x10,0x08,0x10,0x08,0x10,0x08,0x10,0x08,0x0C,0x30,0x03,0xC0,0x00,0x00,0x00,0x00,0x00,0x00 }; // ∪
const uint8_t bmp_L3_3[32] PROGMEM = { 0x00,0x00,0x00,0x00,0x00,0x00,0x00,0x00,0x03,0xC0,0x0C,0x30,0x10,0x08,0x10,0x08,0x10,0x08,0x10,0x08,0x10,0x08,0x10,0x08,0x10,0x08,0x00,0x00,0x00,0x00,0x00,0x00 }; // ∩
const uint8_t bmp_L3_4[32] PROGMEM = { 0x00,0x00,0x00,0x00,0x00,0x00,0x00,0x00,0x00,0x00,0x00,0x00,0x00,0x00,0x07,0x04,0x08,0x88,0x10,0x70,0x00,0x00,0x1F,0xFC,0x00,0x00,0x00,0x00,0x00,0x00,0x00,0x00 }; // ≃
const uint8_t bmp_L3_5[32] PROGMEM = { 0x00,0x00,0x00,0x00,0x00,0x00,0x00,0x00,0x00,0x08,0x00,0x10,0x07,0x24,0x08,0xC8,0x10,0xF0,0x01,0x00,0x1F,0xFC,0x04,0x00,0x08,0x00,0x00,0x00,0x00,0x00,0x00,0x00 }; // ≄
const uint8_t bmp_L3_6[32] PROGMEM = { 0x00,0x00,0x00,0x00,0x00,0x00,0x00,0x00,0x10,0x10,0x10,0x10,0x08,0x20,0x08,0x20,0x04,0x40,0x04,0x40,0x02,0x80,0x02,0x80,0x01,0x00,0x00,0x00,0x00,0x00,0x00,0x00 }; // ∨
const uint8_t bmp_L3_7[32] PROGMEM = { 0x00,0x00,0x00,0x00,0x00,0x80,0x01,0x40,0x01,0x40,0x02,0x20,0x02,0x20,0x04,0x10,0x04,0x10,0x08,0x08,0x08,0x08,0x10,0x04,0x10,0x04,0x00,0x00,0x00,0x00,0x00,0x00 }; // ∧
const uint8_t bmp_L3_8[32] PROGMEM = { 0x00,0x00,0x00,0x00,0x00,0x00,0x00,0x00,0x00,0x00,0x01,0x80,0x01,0x80,0x00,0x00,0x00,0x00,0x00,0x00,0x00,0x00,0x18,0x18,0x18,0x18,0x00,0x00,0x00,0x00,0x00,0x00 }; // ∴
const uint8_t bmp_L3_9[32] PROGMEM = { 0x00,0x00,0x00,0x00,0x00,0x00,0x00,0x00,0x00,0x00,0x18,0x18,0x18,0x18,0x00,0x00,0x00,0x00,0x00,0x00,0x00,0x00,0x01,0x80,0x01,0x80,0x00,0x00,0x00,0x00,0x00,0x00 }; // ∵
const uint8_t bmp_L3_10[32] PROGMEM= { 0x00,0x00,0x00,0x00,0x03,0xF8,0x04,0x00,0x08,0x00,0x10,0x00,0x10,0x00,0x10,0x00,0x08,0x00,0x04,0x00,0x03,0xF8,0x00,0x00,0x1F,0xF8,0x00,0x00,0x00,0x00,0x00,0x00 }; // ⊆
const uint8_t bmp_L3_11[32] PROGMEM= { 0x00,0x00,0x00,0x00,0x1F,0xC0,0x00,0x20,0x00,0x10,0x00,0x08,0x00,0x08,0x00,0x08,0x00,0x10,0x00,0x20,0x1F,0xC0,0x00,0x00,0x1F,0xF8,0x00,0x00,0x00,0x00,0x00,0x00 }; // ⊇
const uint8_t bmp_L3_12[32] PROGMEM= { 0x00,0x00,0x00,0x00,0x03,0xF8,0x04,0x00,0x08,0x00,0x10,0x00,0x10,0x00,0x10,0x00,0x08,0x00,0x04,0x00,0x03,0xF8,0x00,0x00,0x00,0x00,0x00,0x00,0x00,0x00,0x00,0x00 }; // ⊂
const uint8_t bmp_L3_13[32] PROGMEM= { 0x00,0x00,0x00,0x00,0x1F,0xC0,0x00,0x20,0x00,0x10,0x00,0x08,0x00,0x08,0x00,0x08,0x00,0x10,0x00,0x20,0x1F,0xC0,0x00,0x00,0x00,0x00,0x00,0x00,0x00,0x00,0x00,0x00 }; // ⊃

// --- LAYER 4 (共14個) ---
const uint8_t bmp_L4_0[32] PROGMEM = { 0x00,0x00,0x00,0x00,0x00,0x00,0x03,0xE0,0x04,0x10,0x0C,0x18,0x12,0x24,0x11,0x44,0x10,0x84,0x11,0x44,0x12,0x24,0x0C,0x18,0x04,0x10,0x03,0xE0,0x00,0x00,0x00,0x00 }; // ⊗
const uint8_t bmp_L4_1[32] PROGMEM = { 0x00,0x00,0x00,0x00,0x00,0x00,0x03,0xE0,0x04,0x90,0x08,0x88,0x10,0x84,0x10,0x84,0x1F,0xFC,0x10,0x84,0x10,0x84,0x08,0x88,0x04,0x90,0x03,0xE0,0x00,0x00,0x00,0x00 }; // ⊕
const uint8_t bmp_L4_2[32] PROGMEM = { 0x00,0x00,0x00,0x00,0x00,0x00,0x03,0xE0,0x04,0x10,0x08,0x08,0x10,0x04,0x10,0x84,0x11,0xC4,0x10,0x84,0x10,0x04,0x08,0x08,0x04,0x10,0x03,0xE0,0x00,0x00,0x00,0x00 }; // ⊙
const uint8_t bmp_L4_3[32] PROGMEM = { 0x00,0x00,0x00,0x00,0x00,0x00,0x20,0x08,0x20,0x08,0x10,0x10,0x1F,0xF0,0x08,0x20,0x08,0x20,0x04,0x40,0x04,0x40,0x02,0x80,0x02,0x80,0x01,0x00,0x00,0x00,0x00,0x00 }; // ∀
const uint8_t bmp_L4_4[32] PROGMEM = { 0x00,0x00,0x00,0x00,0x00,0x00,0x00,0x00,0x0F,0xE0,0x00,0x20,0x00,0x20,0x00,0x20,0x0F,0xE0,0x00,0x20,0x00,0x20,0x00,0x20,0x0F,0xE0,0x00,0x00,0x00,0x00,0x00,0x00 }; // ∃
const uint8_t bmp_L4_5[32] PROGMEM = { 0x00,0x00,0x00,0x00,0x00,0x00,0x18,0x08,0x14,0x08,0x1A,0x08,0x15,0x08,0x12,0x88,0x11,0x48,0x10,0xA8,0x10,0x58,0x10,0x28,0x10,0x18,0x00,0x00,0x00,0x00,0x00,0x00 }; // ℕ
const uint8_t bmp_L4_6[32] PROGMEM = { 0x00,0x00,0x00,0x00,0x00,0x00,0x1F,0xF8,0x00,0x28,0x00,0x50,0x00,0xA0,0x01,0x40,0x02,0x80,0x05,0x00,0x0A,0x00,0x14,0x00,0x1F,0xF8,0x00,0x00,0x00,0x00,0x00,0x00 }; // ℤ
const uint8_t bmp_L4_7[32] PROGMEM = { 0x00,0x00,0x03,0x80,0x04,0x40,0x08,0x20,0x18,0x30,0x28,0x28,0x28,0x28,0x28,0x28,0x28,0x28,0x18,0x30,0x08,0x20,0x04,0x40,0x03,0x80,0x01,0x40,0x00,0xA0,0x00,0x50 }; // ℚ
const uint8_t bmp_L4_8[32] PROGMEM = { 0x00,0x00,0x0F,0xE0,0x0A,0x50,0x0A,0x48,0x0A,0x48,0x0A,0x50,0x0B,0xE0,0x0A,0x80,0x0B,0x40,0x0A,0xA0,0x0A,0x50,0x0A,0x28,0x0E,0x1C,0x00,0x00,0x00,0x00,0x00,0x00 }; // ℝ
const uint8_t bmp_L4_9[32] PROGMEM = { 0x00,0x00,0x00,0x00,0x1C,0x38,0x14,0x28,0x14,0x28,0x14,0x28,0x14,0x28,0x17,0xE8,0x14,0x28,0x14,0x28,0x14,0x28,0x14,0x28,0x1C,0x38,0x00,0x00,0x00,0x00,0x00,0x00 }; // ℍ
const uint8_t bmp_L4_10[32] PROGMEM= { 0x00,0x00,0x00,0x00,0x1F,0xC0,0x14,0xA0,0x14,0x90,0x14,0x90,0x14,0xA0,0x17,0xC0,0x14,0x00,0x14,0x00,0x14,0x00,0x14,0x00,0x14,0x00,0x1C,0x00,0x00,0x00,0x00,0x00 }; // ℙ
const uint8_t bmp_L4_11[32] PROGMEM= { 0x00,0x00,0x00,0x00,0x00,0x00,0x00,0x00,0x01,0xC0,0x02,0x20,0x04,0x10,0x08,0x10,0x08,0x10,0x0C,0x10,0x0A,0x20,0x09,0xC0,0x08,0x00,0x00,0x00,0x00,0x00,0x00,0x00 }; // ρ
const uint8_t bmp_L4_12[32] PROGMEM= { 0x00,0x00,0x00,0x00,0x00,0x00,0x00,0x00,0x00,0x20,0x00,0x10,0x1F,0xF8,0x00,0x04,0x1F,0xF8,0x00,0x10,0x00,0x20,0x00,0x00,0x00,0x00,0x00,0x00,0x00,0x00,0x00,0x00 }; // ⇒
const uint8_t bmp_L4_13[32] PROGMEM= { 0x00,0x00,0x00,0x00,0x00,0x00,0x00,0x00,0x04,0x20,0x08,0x10,0x1F,0xF8,0x20,0x04,0x1F,0xF8,0x08,0x10,0x04,0x20,0x00,0x00,0x00,0x00,0x00,0x00,0x00,0x00,0x00,0x00 }; // ⇔


// 二維指標矩陣，將陣列完美綁定至 UI 選單
const uint8_t* const symbolBitmaps[4][14] PROGMEM = {
  { bmp_L1_0, bmp_L1_1, bmp_L1_2, bmp_L1_3, bmp_L1_4, bmp_L1_5, bmp_L1_6, bmp_L1_7, bmp_L1_8, bmp_L1_9, bmp_L1_10, bmp_L1_11, bmp_L1_12, bmp_L1_13 },
  { bmp_L2_0, bmp_L2_1, bmp_L2_2, bmp_L2_3, bmp_L2_4, bmp_L2_5, bmp_L2_6, bmp_L2_7, bmp_L2_8, bmp_L2_9, bmp_L2_10, bmp_L2_11, bmp_L2_12 , bmp_L2_13 },
  { bmp_L3_0, bmp_L3_1, bmp_L3_2, bmp_L3_3, bmp_L3_4, bmp_L3_5, bmp_L3_6, bmp_L3_7, bmp_L3_8, bmp_L3_9, bmp_L3_10, bmp_L3_11, bmp_L3_12, bmp_L3_13 },
  { bmp_L4_0, bmp_L4_1, bmp_L4_2, bmp_L4_3, bmp_L4_4, bmp_L4_5, bmp_L4_6, bmp_L4_7, bmp_L4_8, bmp_L4_9, bmp_L4_10, bmp_L4_11, bmp_L4_12, bmp_L4_13 }
};


// =========================================================================
// 🔋 電池電量偵測核心函數 (增加 BLE 動態同步通知)
// =========================================================================
void checkBattery() {
  uint32_t sum = 0;
  adcValue = 0;
  for (int i = 0; i < 16; i++) {
    sum += analogReadMilliVolts(BATTERY_PIN);
    delay(2);
  }
  adcValue = sum / 16.0;

  // 電阻 1:1 分壓還原真實電壓 (ESP32 ADC 預設最大 3.3V)
  float measuredVoltage = 2 * adcValue /1000.0;

  // 加上硬體非線性校正係數
  //measuredVoltage += 0.15; 

  // 將電壓映射為百分比：3.4V (0%) ~ 4.2V (100%)
   percentage = map(measuredVoltage * 100, 340, 420, 0, 100);
  
  if (percentage > 100) percentage = 100;
  if (percentage < 0) percentage = 0;

  batteryLevel = percentage;

  // 🔄【新增關鍵點】：如果藍牙目前處於連線狀態，則將新電量同步回傳給終端裝置
  //if (bleKeyboard.isConnected()) {
    bleKeyboard.setBatteryLevel(batteryLevel);
  //}

  Serial.print("Raw ADC: "); Serial.print(adcValue);
  Serial.print(" | Calc Voltage: "); Serial.print(measuredVoltage);
  Serial.print("V | Level: "); Serial.print(batteryLevel); Serial.println("% (Synced to BLE)");
}

// =========================================================================
// 🚀 點陣圖繪製引擎 (支援線上轉換工具)
// =========================================================================
void renderSymbolPixels(int startX, int startY, int layer, int index) {
  const uint8_t* bitmapPtr = (const uint8_t*)pgm_read_ptr(&(symbolBitmaps[layer - 1][index]));
  if (bitmapPtr == NULL) return;

  for (int y = 0; y < 16; y++) {
    uint8_t leftByte  = pgm_read_byte(bitmapPtr + (y * 2));
    uint8_t rightByte = pgm_read_byte(bitmapPtr + (y * 2) + 1);

    for (int x = 0; x < 8; x++) {
      if ((leftByte >> (7 - x)) & 0x01) {
        u8g2.drawPixel(startX + x, startY + y);
      }
    }
    for (int x = 0; x < 8; x++) {
      if ((rightByte >> (7 - x)) & 0x01) {
        u8g2.drawPixel(startX + 8 + x, startY + y);
      }
    }
  }
}

// --- Siji 狀態列 Icon ---
#define SIJI_BLUETOOTH_ON       0xE00B  
#define SIJI_BLUETOOTH_OFF      0xE02D  

void drawStatusBar(bool isConnected) {
  u8g2.setFont(u8g2_font_6x10_tf); 
  u8g2.drawStr(0, 12, "YMC-PAD");  
  u8g2.setCursor(90, 12); 
  u8g2.print(percentage);
  u8g2.print("%");

  u8g2.setFont(u8g2_font_siji_t_6x10);
  if (isConnected) {
    u8g2.drawGlyph(78, 12, SIJI_BLUETOOTH_ON);   
  } else {
    u8g2.drawGlyph(78, 12, SIJI_BLUETOOTH_OFF);  
  }

  uint16_t batteryGlyph = 0xE242; 
  if (batteryLevel >= 90 && batteryLevel <= 100)     batteryGlyph = 0xE24B;
  else if (batteryLevel >= 80 && batteryLevel < 90)  batteryGlyph = 0xE24A;
  else if (batteryLevel >= 70 && batteryLevel < 80)  batteryGlyph = 0xE249;
  else if (batteryLevel >= 60 && batteryLevel < 70)  batteryGlyph = 0xE248;
  else if (batteryLevel >= 50 && batteryLevel < 60)  batteryGlyph = 0xE247;
  else if (batteryLevel >= 40 && batteryLevel < 50)  batteryGlyph = 0xE246;
  else if (batteryLevel >= 30 && batteryLevel < 40)  batteryGlyph = 0xE245;
  else if (batteryLevel >= 20 && batteryLevel < 30)  batteryGlyph = 0xE244;
  else if (batteryLevel >= 10 && batteryLevel < 20)  batteryGlyph = 0xE243;
  else if (batteryLevel >= 0  && batteryLevel < 10)  batteryGlyph = 0xE242;
  
  u8g2.drawGlyph(114, 12, batteryGlyph); 
  u8g2.drawHLine(0, 15, 128);
}

void updateDisplay(bool isConnected) {
  u8g2.clearBuffer();
  drawStatusBar(isConnected);

  if (isConnected) {
    u8g2.setFont(u8g2_font_7x14_tf);
    u8g2.setCursor(0, 29); 
    u8g2.print("L");
    u8g2.print(currentLayer);
    u8g2.print(": ");
    u8g2.print(symbolShortcuts[currentLayer - 1][currentCursor]);

    for (int i = 0; i < 14; i++) {
      int row = i / 7;
      int col = i % 7;
      int x = col * 18;       
      int y = (row == 0) ? 33 : 49; 

      if (i == currentCursor) {
        u8g2.setDrawColor(1);
        u8g2.drawBox(x, y, 16, 16);    
        u8g2.setDrawColor(0);          
      } else {
        u8g2.setDrawColor(1);          
      }
      renderSymbolPixels(x, y, currentLayer, i);
    }
    u8g2.setDrawColor(1); 
    
  } else {
    u8g2.setFont(u8g2_font_6x12_tf);
    u8g2.drawStr(2, 38, "[ BLE Disconnected ]");
    u8g2.drawStr(6, 52, "Waiting for link...");
  }

  u8g2.sendBuffer();
}

void setup() {
  Serial.begin(57600);
  pinMode(BATTERY_PIN, INPUT);
  //analogSetAttenuation(ADC_11db);
  //analogReadResolution(12);
  
  u8g2.begin();
  u8g2.setFontMode(1);  
  u8g2.setDrawColor(1); 

  // 開機時先量測一次真實電量
  checkBattery();

  bleKeyboard.begin();
  updateDisplay(bleKeyboard.isConnected());
}

void loop() {
  bool connectedNow = bleKeyboard.isConnected();
  static bool lastConnectedState = false;
  char key = keypad.getKey();

  // 每 60 秒異步量測並同步電量一次
  if (millis() - lastBatteryCheck >= batteryInterval) {
    lastBatteryCheck = millis();
    checkBattery();
    updateDisplay(connectedNow); 
  }

  // 🔄 當連線狀態改變時（如剛連上電腦），主動觸發一次電量同步
  if (connectedNow != lastConnectedState) {
    lastConnectedState = connectedNow;
    if (connectedNow) {
      bleKeyboard.setBatteryLevel(batteryLevel); // 確保一連上就立刻將最新真實電量傳給電腦
    }
    updateDisplay(connectedNow);
  }

  if (connectedNow) {
    if (key != NO_KEY) {
      switch(key) {
        case 1: 
          currentLayer++;
          if (currentLayer > 4) currentLayer = 1;
          break;
        case 2: 
          if (currentCursor < 7) currentCursor += 7;
          break;
        case 3: 
          if (currentCursor >= 7) currentCursor -= 7;
          break;
        case 4: 
          currentCursor++;
          if (currentCursor >= 14) currentCursor = 0; 
          break;
        case 7: 
          currentCursor--;
          if (currentCursor < 0) currentCursor = 13;  
          break;
        case 8: 
          bleKeyboard.print(symbolShortcuts[currentLayer - 1][currentCursor]);
          bleKeyboard.print(" "); 
          u8g2.drawHLine(0, 16, 128); 
          u8g2.sendBuffer();
          delay(5);
          break;
        default: 
          break;
      }
      updateDisplay(true);
      //delay(20);
      bleKeyboard.releaseAll();
    }
  } else {
    static unsigned long lastTimer = 0;
    if (millis() - lastTimer > 5) {
      updateDisplay(false);臺
      lastTimer = millis();
    }
  }
}

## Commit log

2026-09-15 Add README for Mathpad PCB files in KiCAD
2026-09-15 YMC-Mathpad Kicad files
    [BlockDiagram.kicad_sch, MCU.kicad_sch, Mathpad.kicad_pcb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]
2026-09-15 Update formatting in Arduino Readme.md
2026-09-15 Fix formatting in Arduino Readme.md
